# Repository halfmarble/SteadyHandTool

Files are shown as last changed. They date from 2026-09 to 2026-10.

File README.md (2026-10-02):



# Steady Hand Tool

> “When you're racing against your own biology, the **story** is just the exhaust; the **science is the engine** and time is the fuel.”

<p align="center">
  Steady Hand Tool v1
  <br>
</p>
<p align="center">
  Steady Hand Tool v1
  <br>
</p>
<p align="center">
  Steady Hand Tool v1
  <br><br><br>
  <em>Steady Hand Tool: Mechanical stability for a wandering hand.</em>
</p>

## See it in Action
<p align="center">
  <a href="https://www.youtube.com/watch?v=Imng8o2QRBg">
    Steady Hand Tool Video
  </a>
  <br>
  <em>Demonstrating the stability and precision of the Steady Hand Tool.</em>
</p>

---

Steady Hand Tool is a manual SMD (Surface Mount Device) assembly stabilizer designed to help makers and professionals prototype PCBs with high precision. Originally created to overcome physical challenges—specifically hand tremors caused by Parkinson’s disease—this tool makes high-accuracy soldering accessible to everyone.

## 🌟 Key Features

* **Stabilized 4-DOF Movement:** Keeps your hand on a steady track while allowing full vertical and horizontal reach.
* **Near-Zero Friction:** Equipped with **14 high-quality metal bearings** and carbon fiber rods for smooth, silent, and effortless operation.
* **Modular Magnetic Coupler:** Features a quick-swap magnetic system for changing tool heads (tweezers, vacuum tips, etc.) in seconds.
* **Purely Mechanical:** No power required, no cables, and no noise. It's always ready to work when you are.
* **Heavy-Duty Base:** A weighted **680g (1.5 lb)** base ensures the arm remains stable even at full extension.
* **Open Source:** Designed to be hacked and customized. Create your own tool heads to suit your specific workflow.

## 🚀 Get Yours

<p align="center">
  <a href="https://www.crowdsupply.com/halfmarble/steady-hand-tool">
    
  </a>
</p>

<p align="center">
  <b>The Steady Hand Tool is coming to <a href="https://www.crowdsupply.com/halfmarble/steady-hand-tool">Crowd Supply</a>.</b><br>
  Sign up to be notified when the campaign launches.
</p>

---

## 🛠 Technical Specifications

* **Reach:** Approximately 250 mm (9.8 in) vertical and horizontal travel.
* **Construction:** 3D-printed components (optimized for PETG/Carbon Fiber) and 8mm carbon fiber rods.
* **Bearings:** MR128ZZ precision shielded bearings.
* **Compatibility:** Designed to support a pair of specialized reverse tweezers optimized for 0805-size components and smaller.

> [!TIP]
> **Looking to build it?** Check out our [Assembly Guide](https://github.com/halfmarble/SteadyHandTool/blob/main/docs/assembly-guide.md) for step-by-step instructions.

## 📂 Repository Structure

```
steady-hand-tool/
├── hardware/
│   └── models/
│       ├── stl/            # Printable parts and tool-head adapters
│       ├── 3rdParty/       # Adapters for third-party tools (PixelPump)
│       ├── 3mf/            # Print plates — orientation and slicer settings, not geometry
│       └── step/           # CAD-fidelity parts (being added part by part)
├── docs/
│   ├── assembly-guide.md   # Step-by-step build instructions
│   └── magnet-polarity.md  # The polarity standard every adapter follows
├── media/                  # Photos used in the docs
├── BOM.md                  # Bill of Materials (the "Shopping List")
├── LICENSE                 # CERN-OHL-S-2.0 License text
└── README.md               # This file
```

### The parts, and which are published

| Part | Status | Notes |
| :--- | :--- | :--- |
| `SteadyHandTool-Pillar.stl` | ✅ Published | Upright strut — carries the pivot pins the arm swings on |
| `SteadyHandTool-Spacer.stl` | ✅ Published | The "fat" spacer — ⌀10.8 body on a ⌀8 spigot. One per bearing set (14 sets) |
| `SteadyHandTool-SpacerSmall.stl` | ✅ Published | The "thin" spacer, same three diameters. One per bearing set |
| `SteadyHandTool-Stopper.stl` | ✅ Published | Split clamp collar for an 8 mm rod, M3 cross screw |
| `SteadyHandTool-Aligner.stl` | ✅ Published | Alignment jig used during assembly |
| `SteadyHandTool-InterfaceRing.stl` | ✅ Published | The ring that interfaces with the tool head (assembly guide, Step 11) |
| `SteadyHandTool-Plate_STEADY_HAND_TOOL.stl` | ✅ Published | Name plate (Step 12) |
| `SteadyHandTool-Plate_half_LOGO_marble.stl` | ✅ Published | Logo plate (Step 12) |
| `InterfaceTweezers.stl`, `InterfaceManualVacuumPen.stl`, `InterfaceTemplate.stl` | ✅ Published | Tool heads. `InterfaceTemplate` is the blank to start your own from |
| Horizontal cage | ⏳ On funding | Assembly guide, Steps 5–6 |
| Vertical cage — three parts | ⏳ On funding | Steps 7–8 |
| Base — printed shell | ⏳ On funding | Filled with steel shot to 680 g (Step 1) |
| Base — machined aluminium | ⏳ On funding | Solid, needs no ballast. CAD, not a printed part |

Quantities per tool are in the [assembly guide](docs/assembly-guide.md), not repeated here.

**Every 3D model will be published when the campaign funds** — that is the commitment, and it is
part of what backing it pays for. Until then the [BOM](BOM.md) and the
[assembly guide](docs/assembly-guide.md) describe the carriage and the base, and the
[magnet polarity standard](docs/magnet-polarity.md) is the full specification any tool head you
design has to match — so designing one is something you can do today, not after the campaign.

---

## ⚙️ Our Mission

"It's the only tool that I have, to help me and others manage our own **slice of PD hell.**"

The Steady Hand Tool is an engineering response to a personal biological war. It exists because "making" is a vital part of staying human. Inspired by the lived reality of Parkinson’s Disease, this tool is engineered to ensure that biological constraints never dictate the boundaries of human creativity.

## 🔧 Our Support

This is a race against time and biology. We invite you to pick up a wrench and help us optimize the hardware for the next generation of makers facing similar constraints. Feedback, CAD iterations, and mechanical refinements are the high-octane fuel that keeps this engine running.

<p align="left">
  <b>10% of the net profit</b> from selling the Steady Hand Tool will go directly to support
  <a href="https://give.michaeljfox.org/halfmarble">Team Fox</a>, the grassroots fundraising program of
  The Michael J. Fox Foundation for Parkinson’s Research.
  <br>
  <em>halfmarble is an independent Team Fox third-party fundraiser.</em>
</p>

---

## License

This project is licensed under the [**CERN-OHL-S-2.0 License**](https://choosealicense.com/licenses/cern-ohl-s-2.0/) - see the [LICENSE](LICENSE) file for details.

## Trademarks

The license above covers this repository’s hardware designs and documentation. It grants no rights to any trademark, trade name, or logo — including the Team Fox and Michael J. Fox Foundation marks, and halfmarble’s own.

---

## Credits

**Photography:** Hero images provided by [Crowd Supply](https://www.crowdsupply.com).

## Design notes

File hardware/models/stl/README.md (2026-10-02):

# Printable parts

Every file in this folder is ready to slice. Quantities and build order are in the
[assembly guide](../../../docs/assembly-guide.md); the [BOM](../../../BOM.md) is the shopping
list for everything you cannot print.

| File | What it is |
| :--- | :--- |
| `SteadyHandTool-Pillar.stl` | Upright strut — carries the pivot pins the arm swings on |
| `SteadyHandTool-Spacer.stl` | The "fat" spacer, ⌀10.8 body on a ⌀8 spigot. One per bearing set |
| `SteadyHandTool-SpacerSmall.stl` | The "thin" spacer, same three diameters. One per bearing set |
| `SteadyHandTool-Stopper.stl` | Split clamp collar for an 8 mm rod, M3 cross screw |
| `SteadyHandTool-Aligner.stl` | Alignment jig used during assembly |
| `SteadyHandTool-InterfaceRing.stl` | The ring the tool head couples to (Step 11) |
| `SteadyHandTool-Plate_STEADY_HAND_TOOL.stl` | Name plate (Step 12) |
| `SteadyHandTool-Plate_half_LOGO_marble.stl` | Logo plate (Step 12) |
| `InterfaceTweezers.stl` | Tweezer head |
| `InterfaceManualVacuumPen.stl` | Manual vacuum pen head |
| `InterfaceTemplate.stl` | The blank — start your own tool head from this one |

Adapters for third-party tools are one level up, in [`3rdParty/`](../3rdParty). Print plates, which
carry orientation and slicer settings rather than geometry, are in [`3mf/`](../3mf).

## Not in this folder yet: the carriage and the base

Five printable parts are still to come, so you will not find them here:

| Part | Where it is used |
| :--- | :--- |
| Horizontal cage | Assembly guide, Steps 5–6 |
| Vertical cage — three parts | Steps 7–8 |
| Base — the printed shell, filled with steel shot to 680 g | Step 1 |

**Every 3D model will be published when the campaign funds** — that is the commitment, and it is
part of what backing it pays for.

They are documented in the meantime, so the design is not a black box while you wait:

- the [assembly guide](../../../docs/assembly-guide.md) shows how the carriage and the base go
  together, in the order you would build them;
- the [BOM](../../../BOM.md) lists what goes inside them — including the ballast, where the shot
  size is fussier than it looks and is worth reading before you buy any;
- the [magnet polarity standard](../../../docs/magnet-polarity.md) is the whole specification a
  tool head has to match. Nothing about it waits on the campaign, so a tool head of your own
  design is something you can build today, with `InterfaceTemplate.stl` as the starting blank.

[The campaign is on Crowd Supply.](https://www.crowdsupply.com/halfmarble/steady-hand-tool)

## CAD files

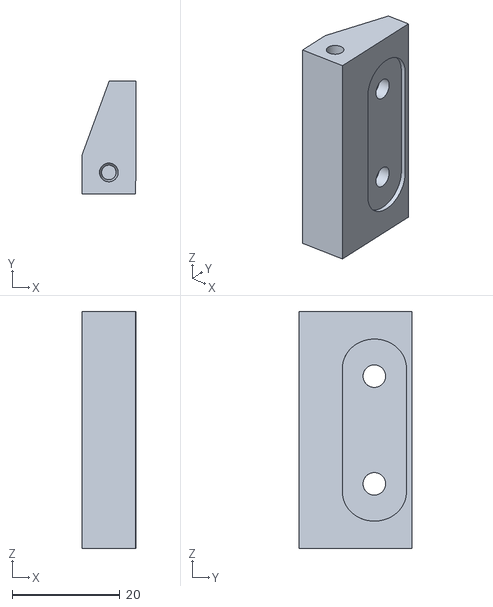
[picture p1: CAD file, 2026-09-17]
hardware/models/stl/SteadyHandTool-Pillar.stl
10.1 x 21.0 x 44.0

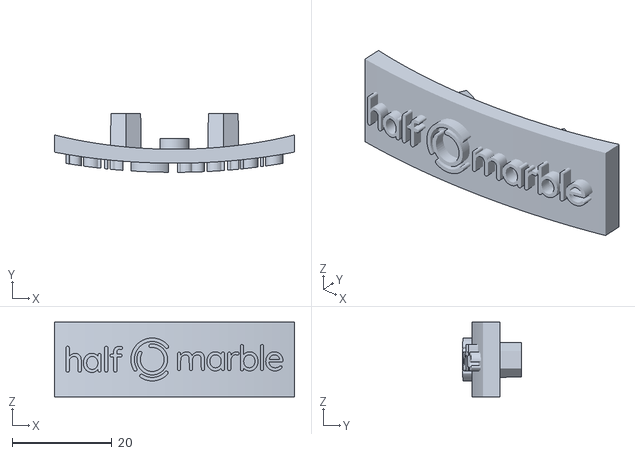
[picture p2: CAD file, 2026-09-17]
hardware/models/stl/SteadyHandTool-Plate_half_LOGO_marble.stl
48.0 x 11.7 x 15.0

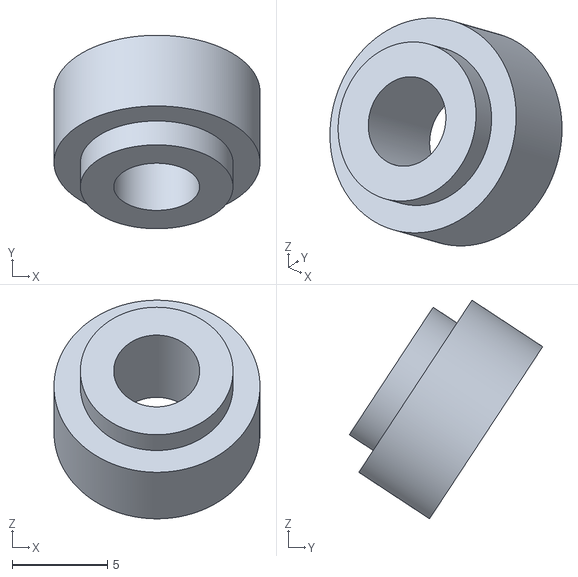
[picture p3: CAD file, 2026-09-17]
hardware/models/stl/SteadyHandTool-Spacer.stl
10.8 x 10.1 x 11.5

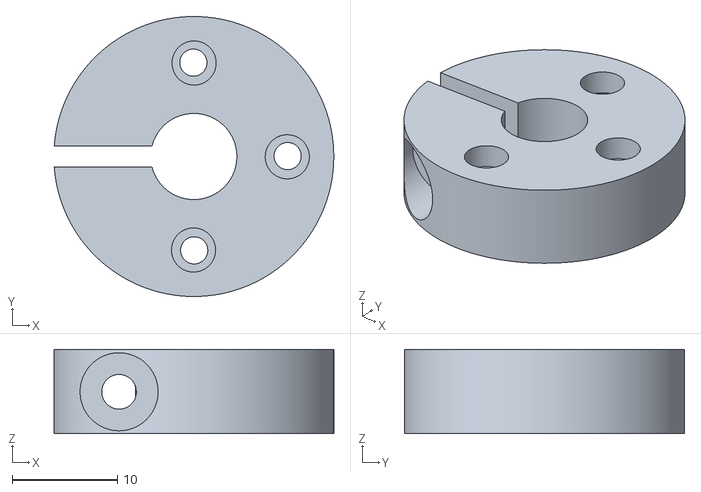
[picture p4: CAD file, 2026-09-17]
hardware/models/stl/SteadyHandTool-Stopper.stl
26.6 x 26.7 x 8.00

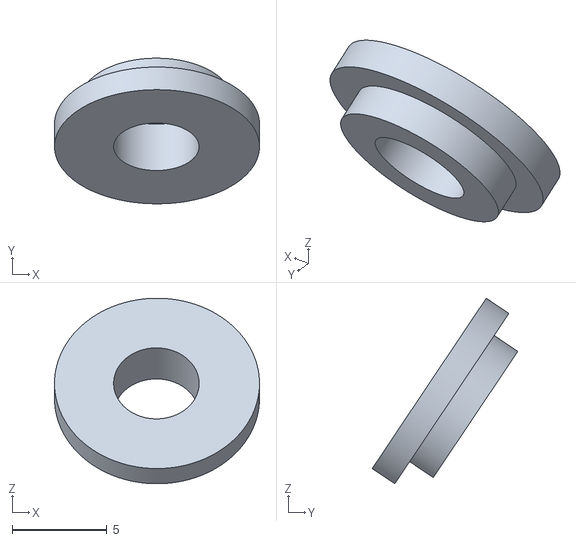
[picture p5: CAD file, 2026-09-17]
hardware/models/stl/SteadyHandTool-SpacerSmall.stl
10.8 x 7.67 x 9.77

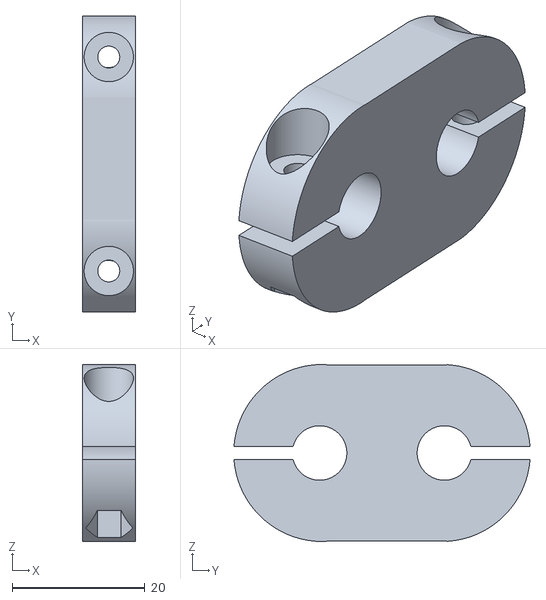
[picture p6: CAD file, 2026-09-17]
hardware/models/stl/SteadyHandTool-Aligner.stl
8.00 x 44.6 x 26.7

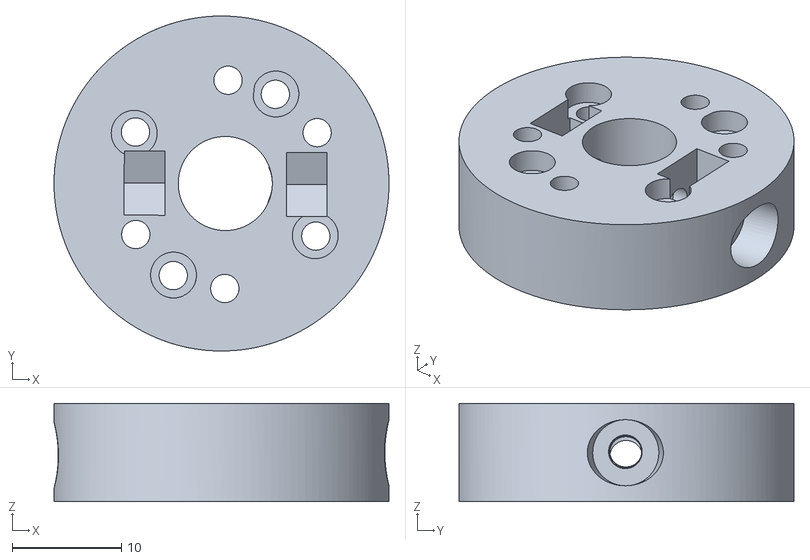
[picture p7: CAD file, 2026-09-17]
hardware/models/stl/SteadyHandTool-InterfaceRing.stl
30.7 x 30.7 x 8.99

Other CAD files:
hardware/models/stl/SteadyHandTool-Plate_STEADY_HAND_TOOL.stl

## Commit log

2026-09-17 Publish the printable structural parts
    Adds the pillar, spacers, stopper, aligner, interface ring and the two logo
    plates, and rewrites the repository structure section to describe what is
    actually here rather than a planned layout. The carriage assembly and the
    bases are not included.
    [SteadyHandTool-Aligner.stl, SteadyHandTool-InterfaceRing.stl, SteadyHandTool-Pillar.stl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]
2026-09-17 Remove the SMD pen 3MF plate
    The two PixelPump adapter STLs stay; the print plate carried settings that
    will be regenerated.
2026-09-17 Move the SMD pen print plate into models/3mf/
    A 3MF is a print plate, not a geometry model, so it does not belong beside
    the STLs. Restored unchanged from the previous commit.
2026-09-19 Point the assembly guide link at the halfmarble org
    The repository moved to halfmarble/SteadyHandTool, so it now sits with
    the entity named in its licence. GitHub redirects the old path, so the
    link was not broken; this is just the canonical URL.
2026-10-02 README: list every part with its publish status; add a README to models/stl
2026-11-05 Add a per-unit print list
    Print.md lists every 3D-printed part of one tool, how many copies to
    print and whether each is published yet, with starting slicer settings
    for PETG-GF.
2026-11-10 Update the printable parts to the current design
    Replaces nine STLs with the current builds, each one solid with no
    non-manifold edges or self-intersections:
    - Pillar, Spacer, SpacerSmall, Stopper, Aligner: rebuilt meshes, same
    geometry and the same assembly frame as before.
    - InterfaceTweezers, InterfaceTemplate, InterfaceManualVacuumPen: magnet
    seats on the d18.0 circle that docs/magnet-polarity.md specifies.
    - InterfaceRing: magnet seats on d18.0, nut pockets moved clear of the
    seats, outside diameter 48.85, sized so that an M3x16 clamp bolt head
    stays inside it.
    Step 11 of the assembly guide and the BOM now call for 2x M3x16 in place
    of 2x M3x10.
2026-11-10 Switch the arm's M4 fasteners to M3
    Pillar, Spacer and SpacerSmall: bolt bores sized for M3 bolts, and the
    Pillar's nut pockets for M3 nuts. Same assembly frame as before.
    The assembly guide and the BOM now list M3 hardware only. Step 11
    counts the four interface rings, one per tool head.
2026-11-10 Update the fastener and magnet counts
    Step 12 counts the clamp screws for each of the four tweezers heads in the
    print list. The magnet count adds the four interface rings, the vertical
    cage and the stopper. The 3.0 mm driver went with the M4 bolts.
2026-11-10 Add a per-part table of fasteners and magnets to the BOM
    Each part that takes a fastener or a magnet, with its M3 bolts by length, its
    nuts and its magnets; the totals match the fastener and magnet counts above.
    The guide writes the short bolt as M3x10, like every other size.
2026-11-10 Update the magnet polarity standard and the Stopper
    - docs/magnet-polarity.md covers every magnet array: base pockets, tool
    heads, both faces of the interface ring and the vertical cage dock.
    - Stopper: no magnet seats. The BOM counts 92 magnets.
    - Printed base listed as a cup and screw-in top; about 590 g of shot.
2026-11-11 Update the rod-interface bolt to M3x12
2026-11-11 Update the spacers to a 3.0 mm bore
    Both spacers now print upright from the file, on a single axis.
2026-11-12 Update the rod-interface bolt to M3x16
2026-11-12 Update the vertical cage plates' bolt and nut rows
2026-11-12 Rename the vertical cage parts: bottom, middle, top
    The vertical cage stack is now named from the bottom up: the part
    listed as "Vertical cage" (SteadyHandTool-CageV.stl) is "Vertical cage,
    bottom" (SteadyHandTool-CageVBottom.stl), and the plate listed as
    "Vertical cage, bottom" is "Vertical cage, middle"
    (SteadyHandTool-CageVMiddle.stl). "Vertical cage, top" is unchanged.
    Print.md and BOM.md follow; no part, count or fastener changes.
2026-11-12 Update the vertical cage to M3x16 bolts only
2026-11-12 Update the Pillar: its bolts form their own thread, no pillar nuts
2026-11-12 Restore the Pillar nut pockets
    The two bearing bolts in each pillar take a nut again: 40 nuts in the kit.
2026-11-13 Update Pillar: self-threading vertical bore ends
2026-11-13 Add the magnet pushers and how to use them
